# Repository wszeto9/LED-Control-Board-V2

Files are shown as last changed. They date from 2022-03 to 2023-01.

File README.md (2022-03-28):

# LED-Control-Board-V2
Version 2 of a easy-to-deploy, low-cost PCBA to control LED lights over Wi-Fi. Designed for use at MIT's East Campus REX event to light up large forts and structures at distances of over 30 ft.

[Interactive BOM](https://htmlpreview.github.io/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)
<h2> Features:</h2>
<ul>

<li>Costs under $10 per Control board </li>
<li>USB-C PD/QC input (12V) for analog RGB strips</li>
<li>USB-C input (5V) for addressible RGB strips</li>
<li>Intended to be used with 12V/1.5A (18W) USB-C` power banks for portability</li>
<li>Panelized in a 4x2 panel of 100x100mm for minimal fabrication costs at JLCPCB</li>
<li>Individual PCBs are designed to be small and not noticible in deployment</li>
<li>Auto-reset circuit for ESP8266 reduces the equipment needed to program boards</li>
<li>Exposed breakout headers allows customization of voltages that are used</li>
<li>LEDs to debug circuits </li>
<li>Programming side (Right) can be cut off and seperated from controller side (Left) to reduce the chips needed to program boards to further reduce cost</li>
</ul>

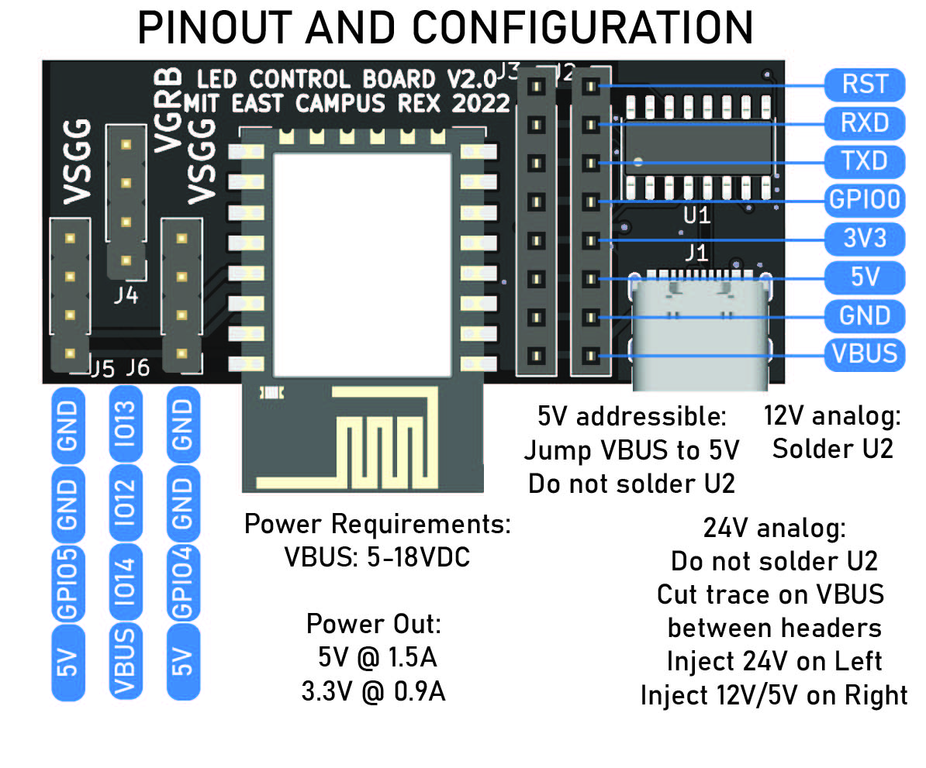
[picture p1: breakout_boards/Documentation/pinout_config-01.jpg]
Pinout

Pinout

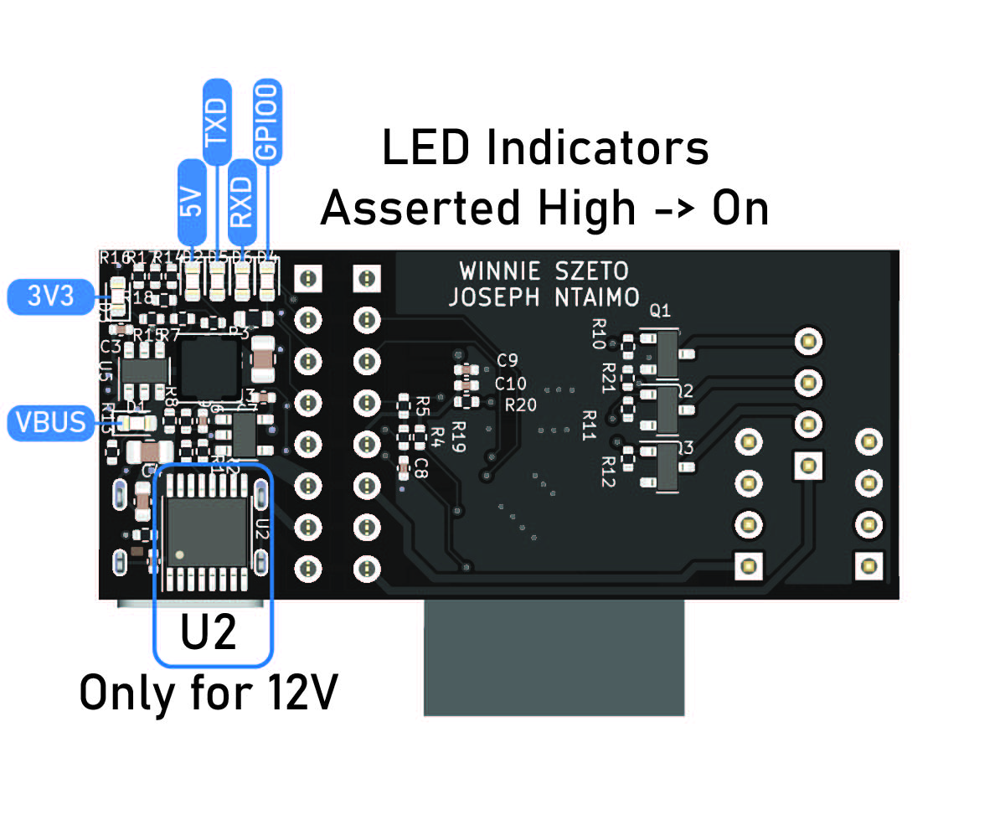
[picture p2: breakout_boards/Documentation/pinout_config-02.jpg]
LED Inducators

LED Indicators

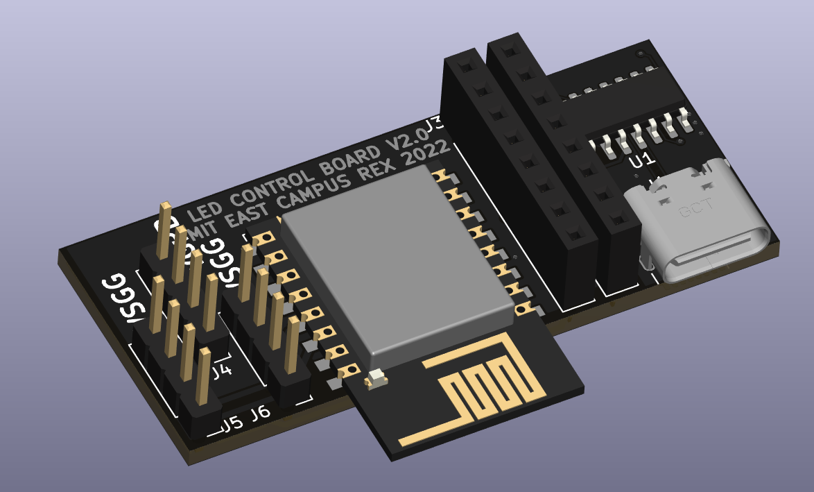
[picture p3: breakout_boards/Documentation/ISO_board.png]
Top_unpopulated

Populated Board

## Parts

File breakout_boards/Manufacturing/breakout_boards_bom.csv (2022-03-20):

Comment | Designator | Footprint | LCSC
1uF | C1,C3 | Capacitor_SMD:C_0402_1005Metric | C52923
10uF | C2 | Capacitor_SMD:C_0603_1608Metric | C96446
22uF | C4,C5 | Capacitor_SMD:C_0805_2012Metric | C45783
10uF | C6,C7 | Capacitor_SMD:C_0402_1005Metric | C15525
100nF | C8,C10 | Capacitor_SMD:C_0402_1005Metric | C1525
10nF | C9 | Capacitor_SMD:C_0402_1005Metric | C15195
LED | D1,D2,D3,D4,D5,D6 | LED_SMD:LED_0603_1608Metric | C72038
USB_C_Receptacle_USB2.0 | J1 | Connector_USB:USB_C_Receptacle_Palconn_UTC16-G | C165948
USB_POWER_HEADER | J2 | Connector_PinSocket_2.54mm:PinSocket_1x08_P2.54mm_Vertical
USB_POWER_HEADER_2 | J3 | Connector_PinSocket_2.54mm:PinSocket_1x08_P2.54mm_Vertical
ANALOG RGB HEADER | J4 | Connector_PinHeader_2.54mm:PinHeader_1x04_P2.54mm_Vertical
ADDRESSIBLE RGB HEADER 1 | J5 | Connector_PinHeader_2.54mm:PinHeader_1x04_P2.54mm_Vertical
ADDRESSIBLE RGB HEADER 2 | J6 | Connector_PinHeader_2.54mm:PinHeader_1x04_P2.54mm_Vertical
10uH | L1 | Inductor_SMD:L_Taiyo-Yuden_NR-40xx | C135263
AO3400A | Q1,Q2,Q3 | Package_TO_SOT_SMD:SOT-23 | C20917
5.1K | R1,R2 | Resistor_SMD:R_0402_1005Metric | C25905
1K | R10,R11,R12,R14,R16,R17,R18 | Resistor_SMD:R_0402_1005Metric | C11702
2K | R13 | Resistor_SMD:R_0402_1005Metric | C4109
330R | R15 | Resistor_SMD:R_0402_1005Metric | C25104
220 | R3 | Resistor_SMD:R_0603_1608Metric | C22962
10K | R4,R5,R9,R19,R20,R21 | Resistor_SMD:R_0402_1005Metric | C25744
100K | R6,R22 | Resistor_SMD:R_0402_1005Metric | C25741
18K | R7 | Resistor_SMD:R_0402_1005Metric | C25762
12K | R8 | Resistor_SMD:R_0402_1005Metric | C25752
CH340C | U1 | Package_SO:SOIC-16_3.9x9.9mm_P1.27mm | C84681
IP2721 | U2 | Package_SO:TSSOP-16_4.4x5mm_P0.65mm | C603176
XC6210B332MR | U3 | Package_TO_SOT_SMD:SOT-23-5 | C424705
MT1470 | U5 | Package_TO_SOT_SMD:TSOT-23-6 | C181781
ESP-12F | U6 | RF_Module:ESP-12E

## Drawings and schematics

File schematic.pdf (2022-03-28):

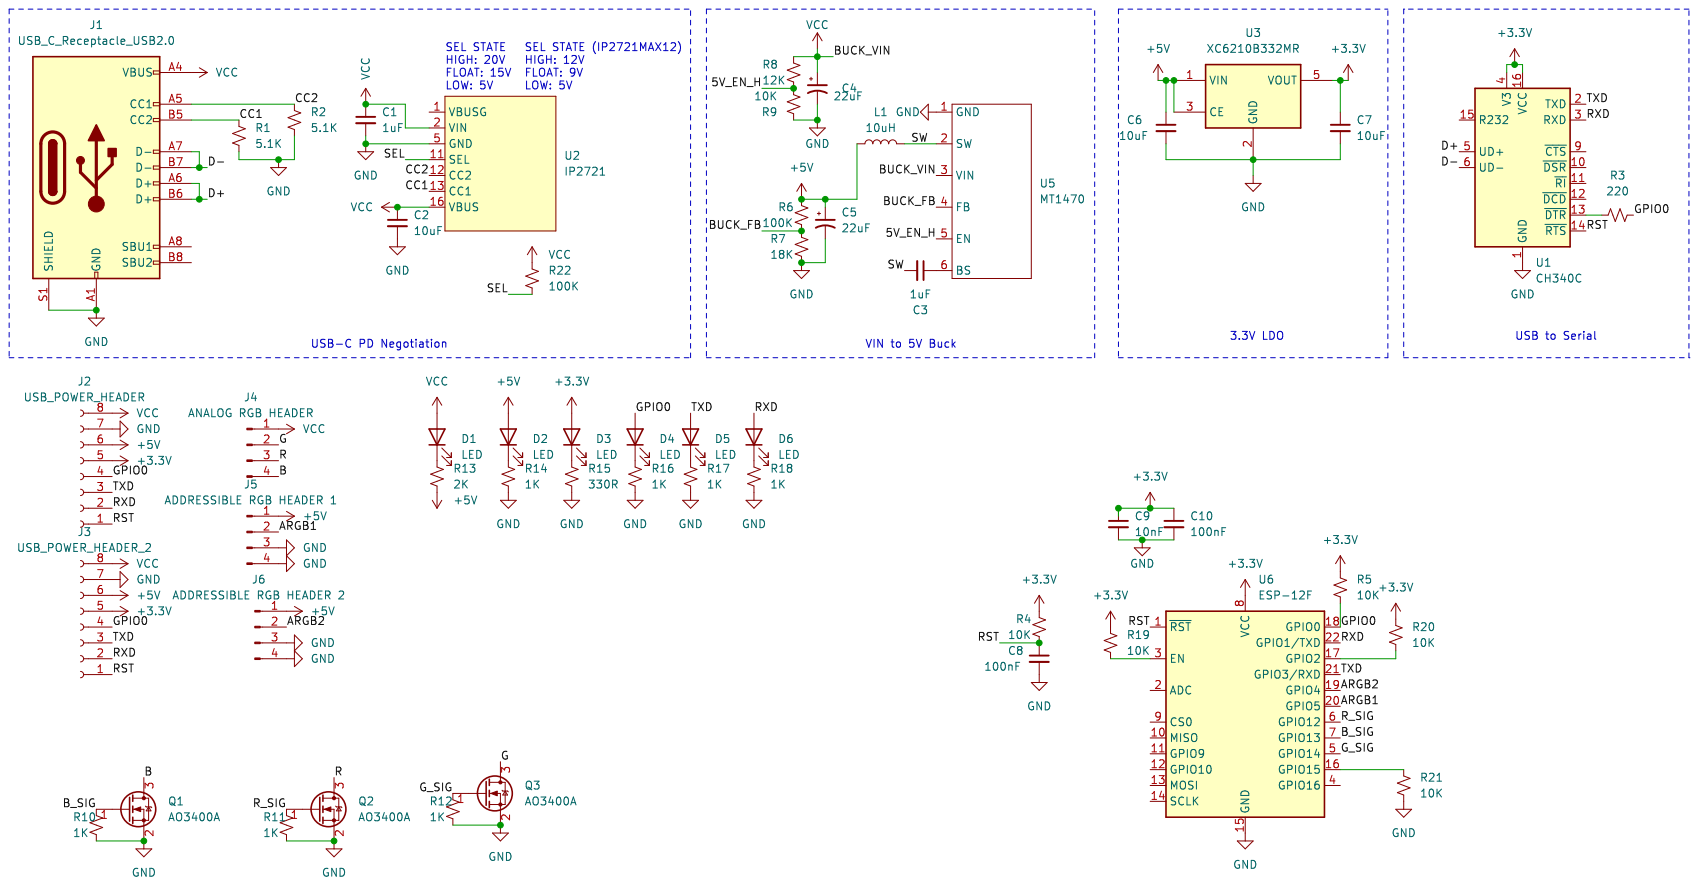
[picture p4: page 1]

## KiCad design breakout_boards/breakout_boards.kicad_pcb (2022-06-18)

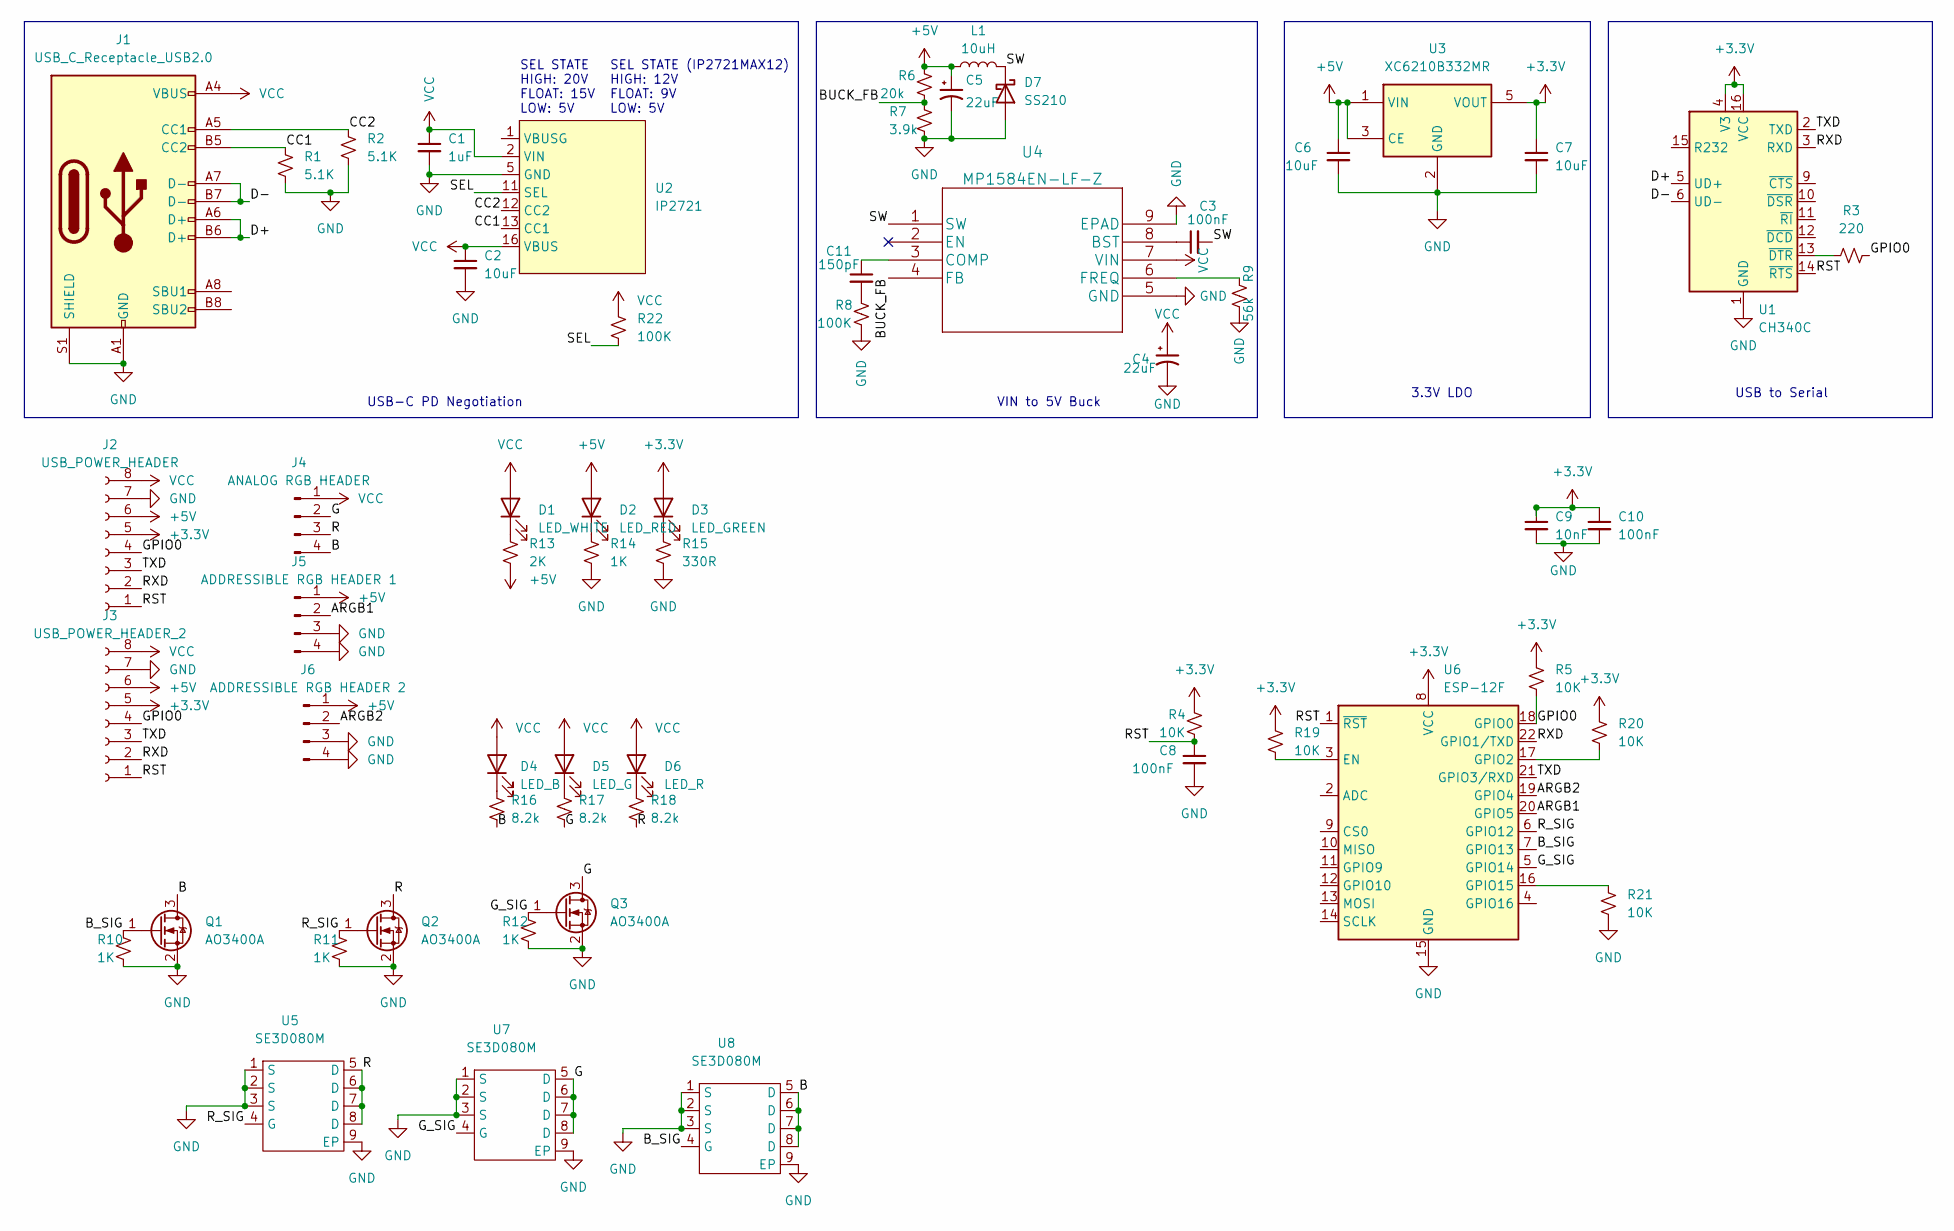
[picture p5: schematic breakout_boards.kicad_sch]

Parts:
C1: 1uF; C_0402_1005Metric; LCSC Part Number C52923
C2: 10uF; C_0603_1608Metric; LCSC Part Number C96446
C3: 100nF; C_0402_1005Metric; LCSC Part Number C52923
C4, C5: 22uF; C_0805_2012Metric; LCSC Part Number C45783
C6, C7: 10uF; C_0402_1005Metric; LCSC Part Number C15525
C8, C10: 100nF; C_0402_1005Metric; LCSC Part Number C1525
C9: 10nF; C_0402_1005Metric; LCSC Part Number C15195
C11: 150pF; C_0402_1005Metric; LCSC Part Number C52923
D1: LED_WHITE; LED_0603_1608Metric; LCSC Part Number C72038
D2: LED_RED; LED_0603_1608Metric; LCSC Part Number C2290
D3: LED_GREEN; LED_0603_1608Metric; LCSC Part Number C72043
D4: LED_B; LED_0603_1608Metric; LCSC Part Number C72043
D5: LED_G; LED_0603_1608Metric; LCSC Part Number C72043
D6: LED_R; LED_0603_1608Metric; LCSC Part Number C72043
D7: SS210; D_SMA
J1: USB_C_Receptacle_USB2.0; USB_C_Receptacle_Palconn_UTC16-G; LCSC Part Number C165948
J2: USB_POWER_HEADER; PinSocket_1x08_P2.54mm_Vertical
J3: USB_POWER_HEADER_2; PinSocket_1x08_P2.54mm_Vertical
J4: ANALOG RGB HEADER; PinHeader_1x04_P2.54mm_Vertical
J5: ADDRESSIBLE RGB HEADER 1; PinHeader_1x04_P2.54mm_Vertical
J6: ADDRESSIBLE RGB HEADER 2; PinHeader_1x04_P2.54mm_Vertical
L1: 10uH; L_Taiyo-Yuden_NR-40xx; LCSC Part Number C135263
Q1, Q2, Q3: AO3400A; SOT-23; LCSC Part Number C20917
R1, R2: 5.1K; R_0402_1005Metric; LCSC Part Number C25905
R3: 220; R_0603_1608Metric; LCSC Part Number C22962
R4, R5, R19, R20, R21: 10K; R_0402_1005Metric; LCSC Part Number C25744
R6: 20k; R_0402_1005Metric; LCSC Part Number C25741
R7: 3.9k; R_0402_1005Metric; LCSC Part Number C25762
R8, R22: 100K; R_0402_1005Metric; LCSC Part Number C25741
R9: 56k; R_0402_1005Metric; LCSC C25796
R10, R11, R12, R14: 1K; R_0402_1005Metric; LCSC Part Number C11702
R13: 2K; R_0402_1005Metric; LCSC Part Number C4109
R15: 330R; R_0402_1005Metric; LCSC Part Number C25104
R16, R17, R18: 8.2k; R_0402_1005Metric; LCSC Part Number C25104
U1: CH340C; SOIC-16_3.9x9.9mm_P1.27mm; LCSC Part Number C84681
U2: IP2721; TSSOP-16_4.4x5mm_P0.65mm; LCSC Part Number C603176
U3: XC6210B332MR; SOT-23-5; LCSC Part Number C424705
U4: MP1584EN-LF-Z; SOIC-8-1EP_3.9x4.9mm_P1.27mm_EP2.62x3.51mm
U5, U7, U8: SE3D080M; DFN-8-1EP_3x3mm_P0.65mm_EP1.55x2.4mm
U6: ESP-12F; ESP-12E

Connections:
+3V3: C7.1, C9.1, C10.1, D3.2 (A), J2.5, J3.5, R4.2, R5.1, R19.2, R20.1, U1.4 (V3), U1.16 (VCC), U3.5 (VOUT), U6.8 (VCC)
+5V: C5.1, C6.1, D2.2 (A), J2.6, J3.6, J5.1, J6.1, L1.1, R6.1, R13.2, U3.1 (VIN), U3.3 (CE)
/ARGB1: J5.2, U6.20 (GPIO5)
/ARGB2: J6.2, U6.19 (GPIO4)
/B: J4.4, Q1.3 (D), R16.2, U8.5 (D), U8.6 (D), U8.7 (D), U8.8 (D)
/BUCK_FB: R6.2, R7.1, U4.4 (FB)
/B_SIG: Q1.1 (G), R10.1, U6.7 (GPIO13), U8.4 (G)
/CC1: J1.B5 (CC2), R1.1, U2.13 (CC1)
/CC2: J1.A5 (CC1), R2.1, U2.12 (CC2)
/D+: J1.A6 (D+), J1.B6 (D+), U1.5 (UD+)
/D-: J1.A7 (D-), J1.B7 (D-), U1.6 (UD-)
/G: J4.2, Q3.3 (D), R17.2, U7.5 (D), U7.6 (D), U7.7 (D), U7.8 (D)
/GPIO0: J2.4, J3.4, R3.2, R5.2, U6.18 (GPIO0)
/G_SIG: Q3.1 (G), R12.1, U6.5 (GPIO14), U7.4 (G)
/R: J4.3, Q2.3 (D), R18.2, U5.5 (D), U5.6 (D), U5.7 (D), U5.8 (D)
/RST: C8.1, J2.1, J3.1, R4.1, U1.14 (~RTS), U6.1 (~RST)
/RXD: J2.2, J3.2, U1.3 (RXD), U6.22 (GPIO1/TXD)
/R_SIG: Q2.1 (G), R11.1, U5.4 (G), U6.6 (GPIO12)
/SEL: R22.2, U2.11 (SEL)
/SW: C3.2, D7.1 (K), L1.2, U4.1 (SW)
/TXD: J2.3, J3.3, U1.2 (TXD), U6.21 (GPIO3/RXD)
GND: C1.2, C2.2, C4.2, C5.2, C6.2, C7.2, C8.2, C9.2, C10.2, D7.2 (A), J1.A1 (GND), J1.A12 (GND), J1.B1 (GND), J1.B12 (GND), J1.S1 (SHIELD), J2.7, J3.7, J5.3, J5.4, J6.3, J6.4, Q1.2 (S), Q2.2 (S), Q3.2 (S), R1.2, R2.2, R7.2, R8.2, R9.2, R10.2, R11.2, R12.2, R14.2, R15.2, R21.2, U1.1 (GND), U2.5 (GND), U3.2 (GND), U4.5 (GND), U4.9 (EPAD), U5.1 (S), U5.2 (S), U5.3 (S), U5.9 (EP), U6.15 (GND), U7.1 (S), U7.2 (S), U7.3 (S), U7.9 (EP), U8.1 (S), U8.2 (S), U8.3 (S), U8.9 (EP)
unnamed: C3.1, U4.8 (BST)
unnamed: C11.1, U4.3 (COMP)
unnamed: C11.2, R8.1
unnamed: D1.1 (K), R13.1
unnamed: D2.1 (K), R14.1
unnamed: D3.1 (K), R15.1
unnamed: D4.1 (K), R16.1
unnamed: D5.1 (K), R17.1
unnamed: D6.1 (K), R18.1
unnamed: R3.1, U1.13 (~DTR)
unnamed: R9.1, U4.6 (FREQ)
unnamed: R19.1, U6.3 (EN)
unnamed: R20.2, U6.17 (GPIO2)
unnamed: R21.1, U6.16 (GPIO15)
VCC: C1.1, C2.1, C4.1, D1.2 (A), D4.2 (A), D5.2 (A), D6.2 (A), J1.A4 (VBUS), J1.A9 (VBUS), J1.B4 (VBUS), J1.B9 (VBUS), J2.8, J3.8, J4.1, R22.1, U2.2 (VIN), U2.16 (VBUS), U4.7 (VIN)

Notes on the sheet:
SEL STATE HIGH: 20V FLOAT: 15V LOW: 5V
VIN to 5V Buck
USB-C PD Negotiation
SEL STATE (IP2721MAX12) HIGH: 12V FLOAT: 9V LOW: 5V
USB to Serial
3.3V LDO

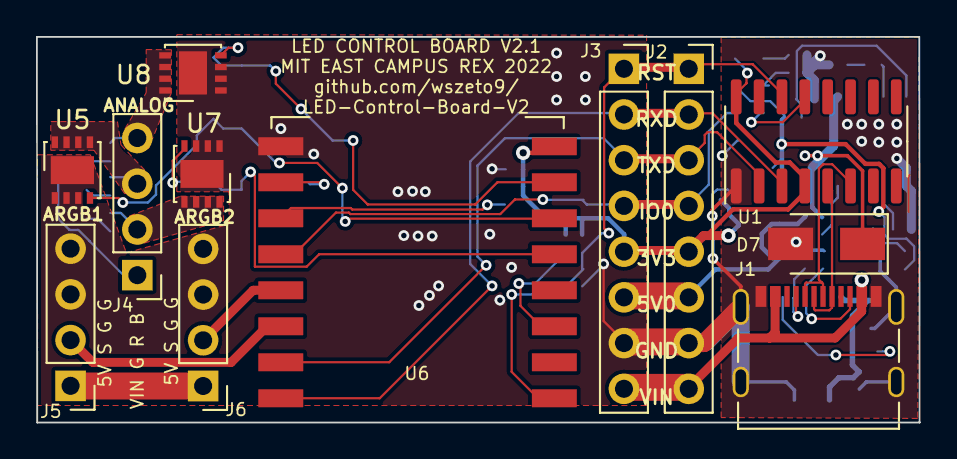
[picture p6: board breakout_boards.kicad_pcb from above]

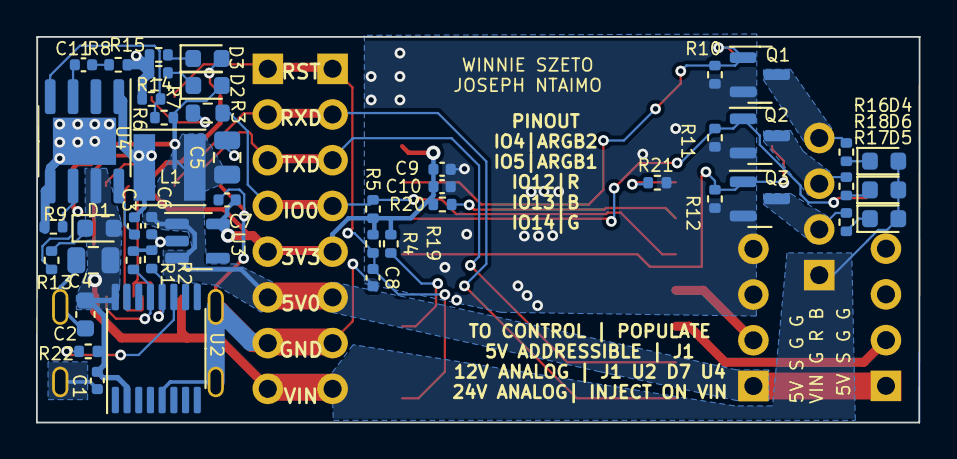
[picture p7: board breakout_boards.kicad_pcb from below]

Board: 2 copper layers, 49.0 x 21.4 mm, 58 parts (46 on the bottom side), 37 nets.

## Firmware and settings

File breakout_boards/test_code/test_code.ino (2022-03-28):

#define R 12
#define B 13
#define G 14
#define ARGB1 5
#define ARGB2 4

void setup() {
  // put your setup code here, to run once:
  pinMode(R,OUTPUT);
  pinMode(G,OUTPUT);
  pinMode(B,OUTPUT);
}

void loop() {
  // put your main code here, to run repeatedly:
  digitalWrite(R,HIGH);
  digitalWrite(G,HIGH);
  digitalWrite(B,HIGH);
  delay(1000);
  analogWrite(B,100);
  delay(500);
  digitalWrite(B,LOW);
  delay(500);
  analogWrite(G,100);
  delay(500);
  digitalWrite(G,LOW);
  delay(500);
  analogWrite(R,100);
  delay(500);
  digitalWrite(R,LOW);
  delay(1000);
}

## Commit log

2022-06-18 V2.1
    Increased current capacity, changed modules to be 30V tolerant
    [breakout_boards.kicad_pcb, breakout_boards.kicad_sch]
2023-01-25 Created V3
    [Buck_5V_Out.kicad_sch, LED_Controller_V3.kicad_pcb, LED_Controller_V3.kicad_sch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]
2023-01-25 Revert "Created V3"
    This reverts commit 6f3930c4007686c3b7fe351275924e18ed986947.
    [Buck_5V_Out.kicad_sch, LED_Controller_V3.kicad_pcb, LED_Controller_V3.kicad_sch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]
